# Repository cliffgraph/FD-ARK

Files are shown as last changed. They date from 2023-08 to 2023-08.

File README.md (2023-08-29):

# FD-ARK
by Harumakkin. 2023/08/29

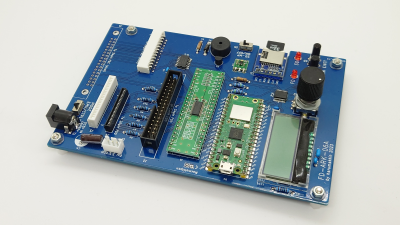
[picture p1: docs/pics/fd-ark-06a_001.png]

**fig.1 FD-ARK-06A**

## What's is this
FD-ARKは、FDDコントローラー＆FDDエミュレーターです。エミュレーターもしくはコントローラの二つの機能を持ち、基板上にある MODE SWによってどちらの機能を使用するかを利用者が選択します。

### （A）FDDコントローラーとしての機能
- MODE SWを"CTRL"にして電源を入れると、FD-ARKはFDDコントローラーとして動作します
- FD-ARKにFDD（フロッピーディスクドライブ）を接続し、2DDフロッピーディスク[^1]から全トラックデータを読み込んでSDカードに保存することができます。保存したデータをフロッピーに書き戻すこともできます。
- SDカード内でフロッピーディスク毎にフォルダ分けする機能がありますで、複数のフロッピーディスクを読み込、SDカードに保存することができます。
- 保存するフォルダは番号で管理されており、ロータリーエンコーダをつまんで回すことでその番号を選ぶことができます。
[^1]:2HDフロッピーディスクには対応していません。

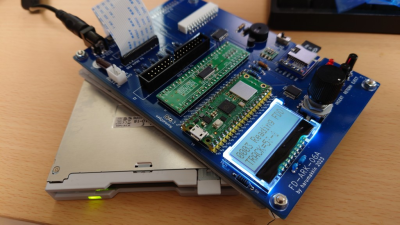
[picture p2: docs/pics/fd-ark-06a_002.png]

**fig.2 FD-ARK-06A with floppy disk drive**

### （B）FDDエミュレーターとしての機能
- MODE SWを"EMU"にして電源を入れると、FD-ARKはFDDエミュレーターとして動作します
- MSX turboR[^2]で、内臓FDDを取り外してFD-ARKを接続することで、FDDの代わりとして機能します。
- FDデータは、FDDコントローラー機能であらかじめSDカード内に保存しておく必要があります。
- MSX本体にアクセスさせるFDデータは、ロータリーエンコーダを回して指定できます。
[^2]:FS-A1STのみで動作確認を行っています。MSX2+ FS-A1WX/FS-A1WSX, MSX turboR FS-A1GT でも動作するはずです。

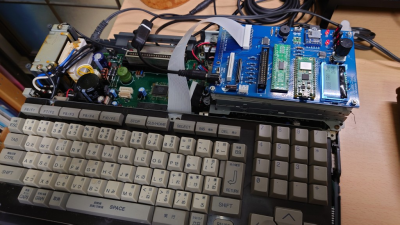
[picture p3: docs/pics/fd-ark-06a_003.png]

**fig.3 FD-ARK-06A with MSXturboR**

## 利用時の注意事項
- MODE SWに切り替えはFD-ARKの電源が切れているときのみ行うことができます。
- また、MSX本体にFD-ARKをつないだままFDDコントローラーに切り替えたり、FDDをFD-ARKをつないだままFDDエミュレーターに切り替えないでください。MSX本体やFDD、FD-ARKが破損する可能性があります。
- MicroSDカードはFATで形式でフォーマットしてください
- イレギュラーなことへの対処はあまり対応していません、FDDアクセス中にフロッピーディスクを抜くとか、SDカードをアクセス中に抜くなどを行うと、FD-ARKやMSX本体がフリーズしたりします。

## FD-ARKを作る
部品表にある部品の収集、プリント基板の製造、組み立て、ファームウェアの書き込みの作業が必要です。完成品はありません。
PCBを発注できて、SOPチップをはんだ付けで来て、Raspberry Pi Picoにu2fファイルを書き込みができる必要があります。

## FD-ARKを使う
### フロッピーディスクを読み込んでＳＤカードに保存する方法(FDDコントローラー)
1. FD-ARKのMODE SWを "CTRL" に切り替えます
1. FD-ARKに、MicroSDカードを装着します。MicroSDカードはWindowsPCなどで事前に FAT 形式でフォーマットしてください。
1. FDDを装着します。FDDは、J2、J3、J4のいずれかのコネクタに接続します。使用実績のあるFDDとその接続箇所はTable 1を参照ンしてください。
1. FD-ARKに、DC5V電源（センタープラス）を接続して電源を入れます
1. LCD画面には、
0001(no file
[←FD][→FD]
と表示されているはずです。
[←FD] の部分が[(空欄)]で表示されている場合は、SD-WPスイッチをOFFに切り替えます。[←FD]が表示されるはずです。
SD-WPスイッチは、SDカードへの書込禁止／許可を切り替えるスイッチです。
1. 読み込みたいフロッピーディスクをFDDへ挿入します。念のためフロッピーディスクのライトプロテクトはＯＮしてください
1. ロータリーエンコーダーを回してフロッピーディスクから読み込んだデータを格納するフォルダを決めます。0001から9999まで選択できます。
1. [←FD] スイッチ（INSERTとシルク印字されているスイッチ）を押します。FDDから読み込みが開始されます。
1. 両面80トラック(全160トラック)の読み込みが完了すると、完了音が鳴り、Completed と表示されます。
1. EJECTとシルク印字されているスイッチを押して、元の画面に戻ります。
1. 格納されたフォルダでは、画面に"FD-DATA"と表示されます。
ex) 0001 FD-DATA
1. 別のFDを読み込みたい場合は、別のフォルダを選択して同様の操作を行います。（どの番号にどのF\フロッピーを読み込んだかは別途メモしておいてください）
1. SDカードをWindowsPCなどで参照すると、\FD-ARK\XXXX フォルダが生成されています。XXXXは保存先に選択したフォルダの番号です。
1. \FD-ARK\XXXX フォルダ内には、COMMENT.TXT と複数のTKnnnn-n.DAT ファイルが生成されています。
1. COMMENT.TXTはLCDに表示されるフォルダ名称が格納されています。編集することができます（半角英数字のみ）。COMMENT.TXTファイルに書き込まれた内容がLCDに表示されるようになります。
### フロッピーディスクへ書き戻す方法(FDDコントローラー)
1. ライトプロテクトをOFFしたフロッピーディスクをFDDに入れます。
1. フロッピーディスクへ書き込むディスクイメージを選択します。
1. [→FD]スイッチ（RETURNとシルク印字されているスイッチ）を押します。FDDへの書き込みが開始されます。

**Table 1. FDDコントローラー・モードで実績のあるFDD**
||型番|メーカー|備考|
|:-:|:-|:-|:-|
|J2|YD-702D-6238D|YE DATA|J8をFDDの電源につなげる|
|J2|D353M3D|MITSUMI|J8をFDDの電源につなげげる|
|J3|EME213MU|Matsushita Electronic Components|FFC 1.25mmピッチ,24ピン,電極逆面を使用する|
|J4|YD-702J-6637J|YE DATA|FFC 1.00mmピッチ,26ピン,電極逆面を使用する||

### MSX本体に接続してフロッピーディスクの代わりとして使用する(FDDエミュレータ)
1. FD-ARKのMODE SWを "EMU" に切り替えます
1. FD-ARKに、MicroSDカードを装着します。事前にFDDコントローラーモードでなにがしかのフロッピーディスクイメージを保存しておく必要があります。
1. FD-ARKのJ5とMSX本体をフラットフレックスケーブルで接続します。動作確認を行った機種はFS-A1STのみです
1. FD-ARKに、DC5V電源（センタープラス）を接続して電源を入れます
1. ロータリーエンコーダーを回して、使用したいフロッピーディスクイメージを選択します。[INSERT]スイッチを押すと選択が確定します（フロッピーディスクをドライブに入れている状態になる）。INSERTされているディスクイメージは番号の前に"*" が表示されます。この状態でロータリーエンコーダーを回して別の番号を表示しても、"*"が表示されているフロッピーディスクイメージがそのまま使用されます。
ex) *0001 FD-DATA
1. [EJECT]スイッチを押すと、フロッピーディスクを取り出した状態にすることができます。
1. MSX本体の電源を入れます。
1. フロッピーディスクイメージを選択していて、そのイメージがブート可能な内容ならそのフロッピーディスクの内容が起動するはずです。

### MicroSDカード
FDDコントローラーモードでディスクイメージをSDカードに保存すると、SDカードにはFD-ARKフォルダが作成され、ディスクイメージはそのフォルダ内に作成される番号フォルダに下記込まれます
```
FD-ARK/
  ├ 0001/
  ├ 0002/
      :
```
番号フォルダ内には、160個のTKnnnn-n.DATファイルとCOMMENT.TXTファイルが格納されています。
１トラックにつき１つのファイルで、TKnnnn-n.DATはフロッピー１トラック分のデータですnnnnはトラック番号。-nはサイド番号です。
.DATファイルの先頭には少しの管理情報と、FDDのREAD DATA端子から出力されているデータを4MHzでサンプリングした情報がそのまま格納されています。
セクタ構造など一切確認作業を行わず生の出力データをそのまま保存しているので.DATファイルの内容が正しいかどうかの保障はありません。

## LICENSEと利用に関する注意事項
1. FD-ARKのファームウェアとそのソースコード、回路図データおよび資料ファイルは MIT License で配布されます。ただし、FD-ARK は、FatFsを使用しています。FatFsのソースコードの扱いに関してはFatFsのLICENSEに従ってください。
2. 本作品は同人ハードウェア＆ソフトウェアです。本作品の設計およびソフトウェアは品質を保証していません。MSX本体、フロッピーディスクドライブ、およびフロッピーディスクとそのデータが故障、破損したとしても自身で責任を負える方のみ本作品をご利用ください。特にハードウェアの製作を伴いますのでリスクがあります。製作の腕に自身のある方のみご利用ください。
3. 本作品の設計資料とソースコードの改変や改造、また、別の作品への利用、商用利用は自由です。ただし、1. 2.の制限を超える利用は各自でその責任と義務を負ってください。

## FD-ARKが使用しているソフトウェア
### FatFs
Copyright (C) 20xx, ChaN, all right reserved.
http://elm-chan.org/fsw/ff/00index_e.html

## 余談
1. FD-ARK製作の経緯：
当初、FDX68シールドという作品がBOOTHで売られていて[^3]、その装置はフロッピーディスクを読みだすことができ、またFDDエミュレータとして使用することもできるものらしいという漠然とした知識だけありました。そういう物があるのかぐらいに捉えていて、自身は必要性を感じていませんでした。しかしある時にふとゲーム保存協会のツイート[^4]が目にとまり、国立国会図書館@NDLJPフロッピーディスク長期保存対策に関する調査報告書というの知りました。これには様々な理由でフロッピーディスクは劣化するものであり、劣化するとフロッピーディスクは使用できなくなってしまうと書かれていました。自身が所有しているMSXに関するフロッピーディスクは30年を超えている物が多く、報告書との出会いは、結果、これらフロッピーディスクに危機感を募らせてしまうことになりました。FDX68シールド、ぜひとも欲しいとなったわけですが、いつも売り切れでこれがなかなか購入できません。調査報告書では似たようなツールにKryoFluxというものを紹介していました。それが公式ページから今でも購入可能と書かれていたので、購入してみることにしました。ただちゃんと調べてから購入すれば良かったのですが、てっきりFDX68のようにKryoFluxにもFDDエミュレータの機能があると思い込んでいてこれが失敗でした。発注後に取説書読んでそれに気が付いたわけですが、同時にFDDって意外とシンプルな仕組みなんだとその時に知りました。これならKryoFluxで読み込んだデータを使用するFDDエミュレータを自分でも作れるだろう、いや作ってしまえと思うに至りました。しっかり作ろうとすると細部が大変になりますのでフロッピーディスクのイメージ化機能もいっしょに作ってしまえば、データフォーマットも独自定義できるしもっと楽に作れると思い、結果、今回のFD-ARKになりました。KryoFluxはKryoFluxで、FD-ARKが失敗した時のためにとフロッピーディスクのイメージ化に今でも使用しています。また、FD-ARKで読み出して、そして書き出した後に、正しく読み書きできているかをKryoFluxでチェックするなんてことに使用しています。
自分自身が所有するフロッピーディスクのためだけに作成したので、3.5"2DD以外の対応は考えていません。
[^3]: https://booth.pm/ja/items/4451666
[^4]: https://twitter.com/gamepres/status/1648638490765295619

2. FDアーカイバを意味した"FD-ARC"と命名するつもりが、間違って"FD-ARK"と名付けてしまいました。ただ、"ARK"は聖書に出てくる十戒石板をおさめた箱を意味するので、大事な物をしまっておくという意味で FD-ARK のままとしました。

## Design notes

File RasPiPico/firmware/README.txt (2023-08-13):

ビルドの方法

> mkdir build
> cd build
> cmake -G "NMake Makefiles" ..
> nmake

build/fd-ark/に、fd-ark.uf2　が生成される.

2023/6/11 Harumakkin.

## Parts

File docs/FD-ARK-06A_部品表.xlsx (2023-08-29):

 |  |  |  |  |  | 2023-08-29
FD-ARK-06A
記号 | 型番 | 個数 | 部品スペック、他 | 購入元 |  | URL | 備考
C1, C2, C4 | 104 | 3 | セラミックコンデンサ 0.1uF
C3 | 105 | 1 | セラミックコンデンサ 1uF
C5 | 100uF | 1 | 電解コンデンサ 100uF
J1 | HIF3BA-34PA-2.54DS(63) | 1 | ボックスヘッダ34P(L形・MILスタンダード) | 千石電商 | ー | https://www.sengoku.co.jp/mod/sgk_cart/detail.php?code=6AD3-6HHL
J2 | 217034SE | 1 | ボックスヘッダ 34P 基板取付け【217034SE】 | マルツオンライン | ー | https://www.marutsu.co.jp/pc/i/10624/
J8 | S3B-XH-A(LF)(SN) | 1 | 【2.5mm】XHコネクタ 基板用ポスト 3P L型 | 千石電商 |  | https://www.sengoku.co.jp/mod/sgk_cart/detail.php?code=6AN6-ABMD
D1 | 1N4001 | 1 | 整流用ダイオード | 千石電商 |  | https://www.sengoku.co.jp/mod/sgk_cart/detail.php?code=EEHD-4V5C
IC1 | TC74HC07AF(F) | 1 | 6回路 バッファ オープンドレイン CMOS SOP14 | マルツオンライン | ー | https://www.marutsu.co.jp/pc/i/444802/
IC2 | MCP23S08-E/SS | 1 | IC XPNDR 10MHZ SPI 20SSOP | マルツオンライン | ー | https://www.marutsu.co.jp/pc/i/13274024/
J3 | 24FE-BT-VK-N | 1 | JST FPC/FFC コネクタ、24極、1.25mm、スルーホール | マルツオンライン | ー | https://www.marutsu.co.jp/pc/i/2565396/
J4 | HLW26S-2C7LF | 1 | CONN FFC FPC VERT 26POS 1MM PCB | マルツオンライン | ー | https://www.marutsu.co.jp/pc/i/12839834/
J5 | 24FE-ST-VK-N | 1 | JST FPC/FFC コネクタ、24極、1.25mm、スルーホール | マルツオンライン | ー | https://www.marutsu.co.jp/pc/i/2565397/
D2,D3 | LED | 2 | 低消費３ｍｍ赤色ＬＥＤ ６２５ｎｍ １ｍＡ 10個パック | 秋月電子 | I-16908 | https://akizukidenshi.com/catalog/g/gI-16908/
J6 | AE-LLCNV-LVCH16T245 | 1 | １６ビット双方向レベル変換モジュール | 秋月電子 | K-15696 | https://akizukidenshi.com/catalog/g/gK-15696/
J7 | MJ-179PH | 1 | ２．１ｍｍ標準ＤＣジャック（４Ａ） | 秋月電子 | C-06568 | https://akizukidenshi.com/catalog/g/gC-06568/
LCD1 | AQM1602Y-NLW-FBW | 1 | ＬＣＤモジュール １６×２行 白色バックライト付 白文字／黒背景 | 秋月電子 | P-12486 | https://akizukidenshi.com/catalog/g/gP-12486/ | AQM1602Y-FLW-FBWなどでもOK。お好みで
LS1 | PKM13EPYH4000-A0 | 1 | 圧電スピーカー（圧電サウンダ）（１３ｍｍ） | 秋月電子 | P-04118 | https://akizukidenshi.com/catalog/g/gP-04118/
Q1 | 2N7000 | 1 | ＭＯＳＦＥＴ ２Ｎ７０００ | 秋月電子 | I-09723 | https://akizukidenshi.com/catalog/g/gI-09723/
S1,S2,S3 | TVDP01-G73BB | 3 | タクトスイッチ ＴＶＤＰ０１－Ｇ７３ＢＢ（黒） | 秋月電子 | P-09824 | https://akizukidenshi.com/catalog/g/gP-09824/
S4,S5 | SS12D00G3 | 2 | スライドスイッチ １回路２接点 基板用 | 秋月電子 | P-15707 | https://akizukidenshi.com/catalog/g/gP-15707/
U1 | RaspberryPi Pico | 1 | RaspberryPi Pico | 秋月電子 | M-16132 | https://akizukidenshi.com/catalog/g/gM-16132/
－ | PHA-1x40SG | 1 | 細ピンヘッダ １×４０ （黒） ※RaspberryPi Pico、AE-LLCNV-LVCH16T245で使用する | 秋月電子 | C-06631 | https://akizukidenshi.com/catalog/g/gC-06631/
U2 | EC12E2420801 | 1 | ロータリーエンコーダ（２４クリックタイプ） | 秋月電子 | P-06357 | https://akizukidenshi.com/catalog/g/gP-06357/
U4 | AE-XC9306-3V3 |  | ＸＣ９３０６使用同期整流昇降圧ＤＣ／ＤＣコンバータキット ３．３Ｖ版 | 秋月電子 | K-16055 | https://akizukidenshi.com/catalog/g/gK-16055/
U3 | MicroSD Car Socket | 1 | Aideepen5個セットマイクロSDストレージ拡張ボードマイクロSDカードメモリシールドモジュール | Amazon | ー | https://www.amazon.co.jp/gp/product/B07MB9TS13/ref=ppx_yo_dt_b_asin_title_o03_s00?ie=UTF8&psc=1
R1,R2 | 10k | 2 | 1/4w 抵抗 |  | ー
R3,R4 | 4.7k | 2 | 1/4w 抵抗 |  | ー
R5-11 | 1k | 7 | 1/4w 抵抗 |  | ー
2023-08-12 | ・初版
2023-08-29 | ・C1, C2, C4, C3 の部品スペックの誤記を修正した
 | ・R3,R4の型番の誤記を修正した

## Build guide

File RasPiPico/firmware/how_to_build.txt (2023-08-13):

（１）Developer PowerShell for VS 2019 を開く
（２）fddpurser フォルダと同階層に、build フォルダを作成する。
（３）build フォルダへ移動する
（４）下記を実行する
	> set PICO_SDK_PATH "C:\Pico\pico-sdk"	*1
	> cmake -G "NMake Makefiles" ..
（５）ビルド実行
	> nmake
（６）build\fddpurser\ フォルダに、fddpurser.uf2 ファイルが出来上がればOK。

*1: "C:\Pico\pico-sdk" は、pico-sdkを格納している場所へのパス。環境に合わせて変更すること。

以上

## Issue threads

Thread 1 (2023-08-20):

抵抗（R3,R4）について

hoborakuten, 2023-08-20:
初めまして。

FD-ARKを作成したいと思い、部品を調達中ですが、一つ確認させてください。
抵抗（R3,R4）の抵抗は4.8kΩで正しいでしょうか。
当方電子工作初心者なのですが、4.8kΩの抵抗がどこの店にもありません。

ご助言いただけると非常に助かります。

cliffgraph, 2023-08-29:
こんにちは、ご指摘ありがとうございます。
部品表の記載ミスでした。すみません。

セラミックコンデンサ
C1, C2, C4 の部品スペック 0.01uF は  0.1uF が正しく、
C3 の部品スペック 0.1uF は  1uF が正しいです。

抵抗　R3,R4の型番は、4.8kは間違いで、4.7kが正しいです。

hoborakuten, 2023-08-29:
お忙しいところ、迅速な対応いただきありがとうございました。
動作確認の報告ができるよう作成していきたいと思います。

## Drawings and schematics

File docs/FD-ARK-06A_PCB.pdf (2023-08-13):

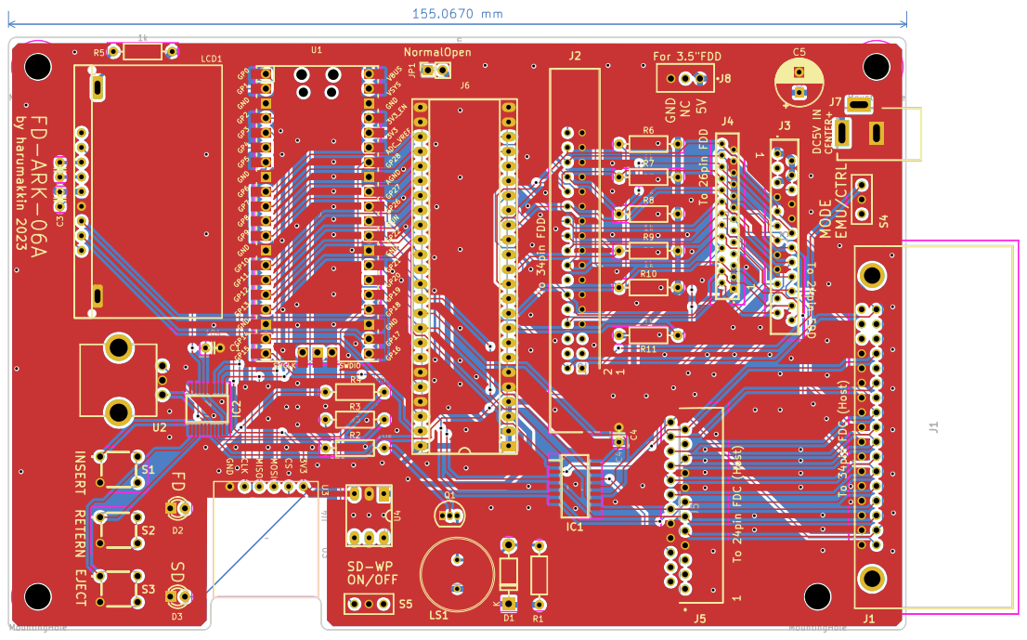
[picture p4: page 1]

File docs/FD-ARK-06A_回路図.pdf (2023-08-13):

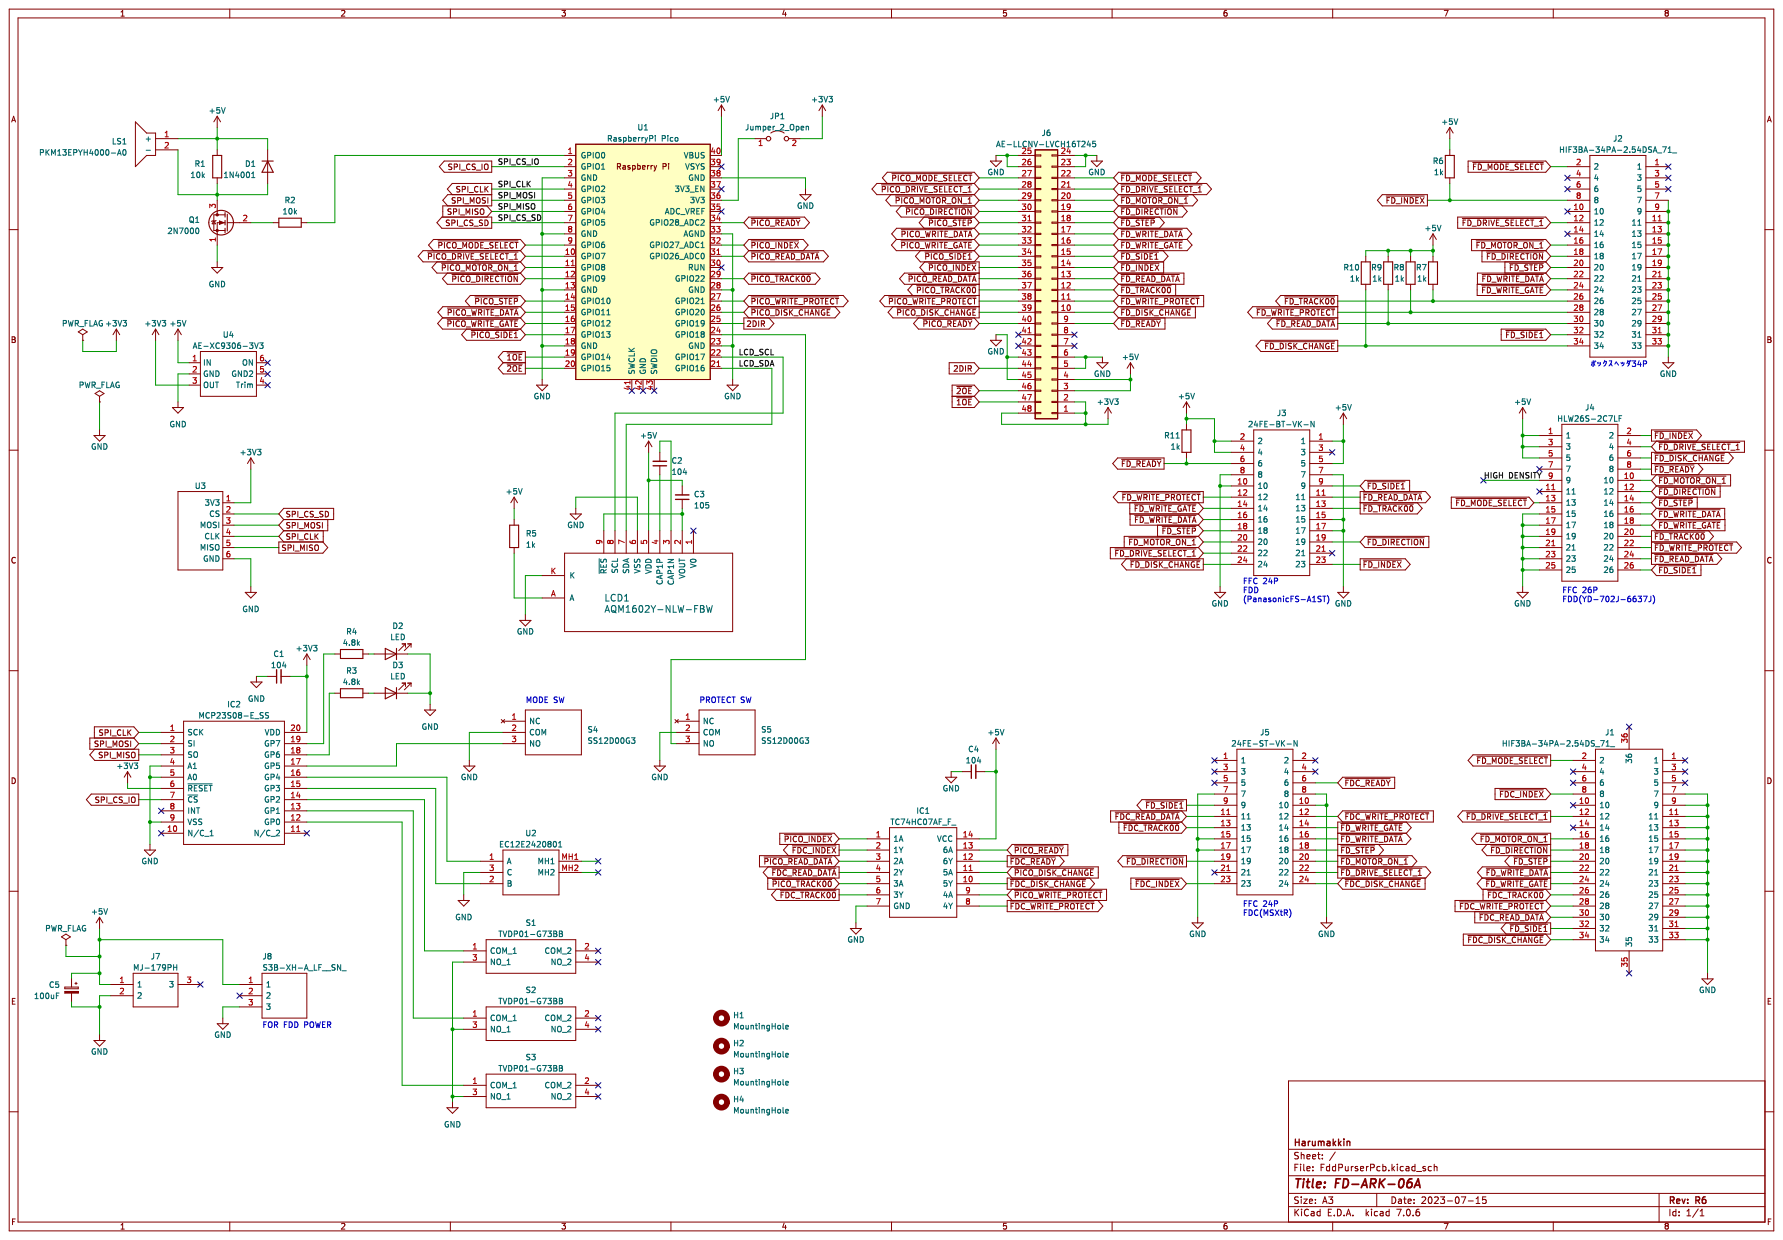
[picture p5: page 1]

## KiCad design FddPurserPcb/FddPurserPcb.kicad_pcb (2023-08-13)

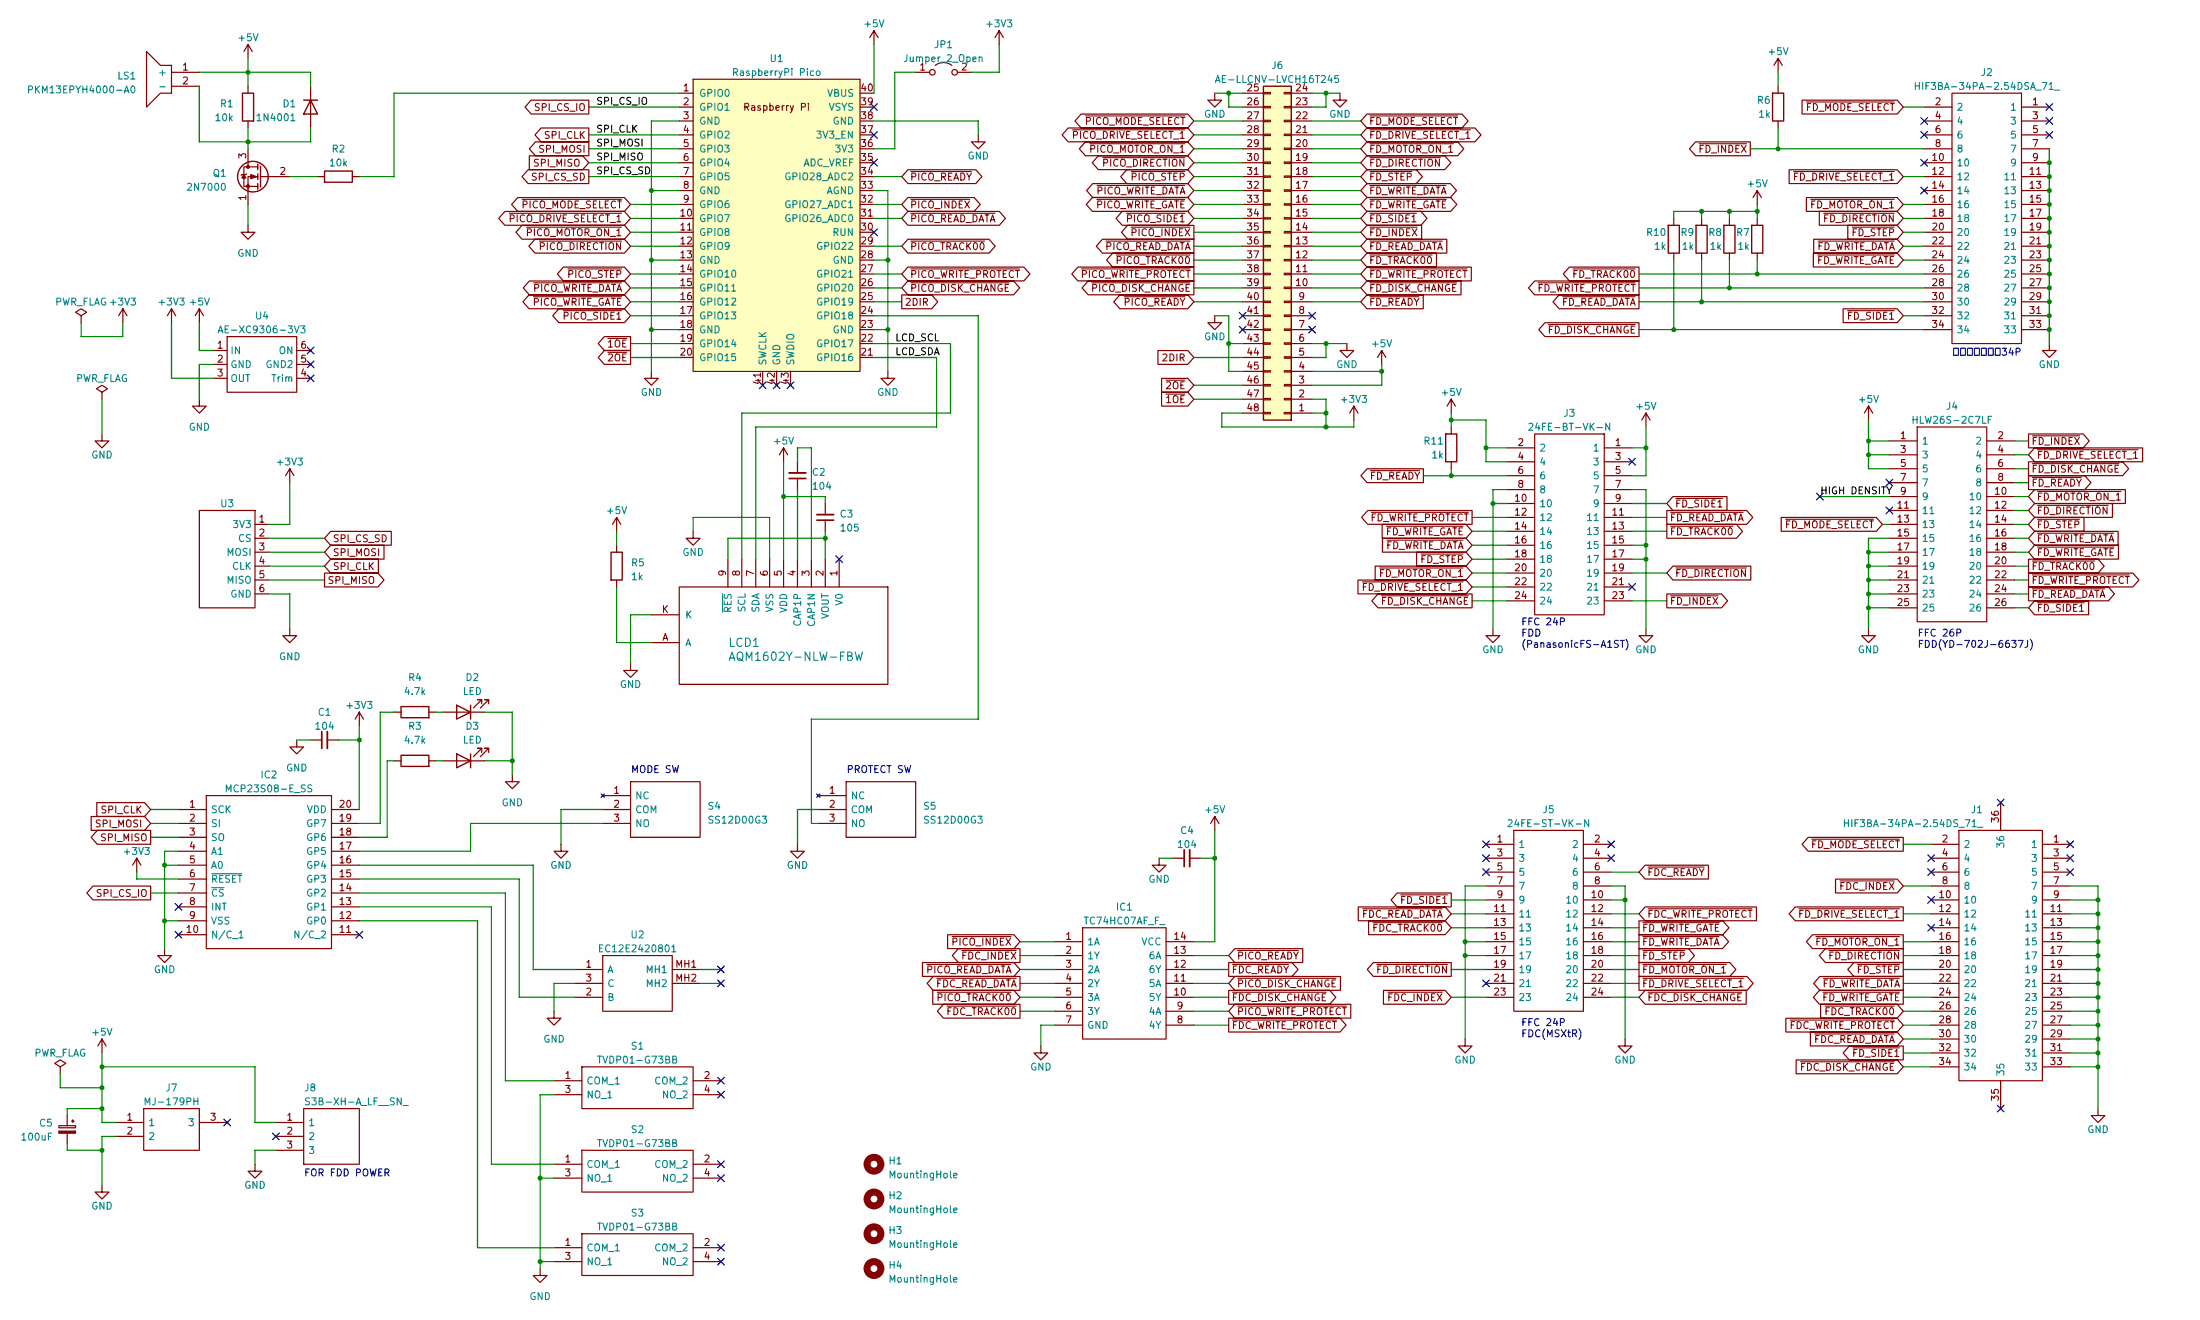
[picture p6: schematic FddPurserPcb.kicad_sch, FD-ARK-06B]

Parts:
C1, C2, C4: 104; C_Rect_L4.5mm_W3.5mm_P2.54mm
C3: 105; C_Rect_L4.5mm_W3.5mm_P2.54mm
C5: 100uF; CP_Radial_D8.0mm_P3.50mm
D1: 1N4001; D_DO-41_SOD81_P10.16mm_Horizontal
D2, D3: LED; LED_D3.0mm
H1, H2, H3, H4: MountingHole; MountingHole_4.3mm_M4
IC1: TC74HC07AF_F_; SOIC127P780X190-14N; Manufacturer_Part_Number TC74HC07AF(F)
IC2: MCP23S08-E_SS; SOP65P780X200-20N; Manufacturer_Part_Number MCP23S08-E/SS
J1: HIF3BA-34PA-2.54DS_71_; HIF3BA34PA254DS71; Manufacturer_Part_Number HIF3BA-34PA-2.54DS(71)
J2: HIF3BA-34PA-2.54DSA_71_; SHDR34W60P254_2X17_6250X850X2730P; Manufacturer_Part_Number HIF3BA-34PA-2.54DSA(71)
J3: 24FE-BT-VK-N; 24FEBTVKN; Manufacturer_Part_Number 24FE-BT-VK-N
J4: HLW26S-2C7LF; HLW26S2C7LF; Manufacturer_Part_Number HLW26S-2C7LF
J5: 24FE-ST-VK-N; 24FESTVKN; Manufacturer_Part_Number 24FE-ST-VK-N
J6: AE-LLCNV-LVCH16T245; DIP-48_W15.24mm_Socket_LongPads
J7: MJ-179PH; MJ179PH_N; Manufacturer_Part_Number MJ-179PH
J8: S3B-XH-A_LF__SN_; S3BXHALFSN; Manufacturer_Part_Number S3B-XH-A(LF)(SN)
JP1: Jumper_2_Open; PinSocket_1x02_P2.54mm_Vertical
LCD1: AQM1602Y-NLW-FBW; AQM1602Y-NLW
LS1: PKM13EPYH4000-A0; PKM13EPYH4002-B0; Manufacturer_Part_Number PKM13EPYH4000-A0
Q1: 2N7000; TO-92_Inline
R1, R2: 10k; R_Axial_DIN0207_L6.3mm_D2.5mm_P10.16mm_Horizontal
R3, R4: 4.7k; R_Axial_DIN0207_L6.3mm_D2.5mm_P10.16mm_Horizontal
R5, R6, R7, R8, R9, R10, R11: 1k; R_Axial_DIN0207_L6.3mm_D2.5mm_P10.16mm_Horizontal
S1, S2, S3: TVDP01-G73BB; TVDP01G73BB; Manufacturer_Part_Number TVDP01-G73BB
S4, S5: SS12D00G3; Manufacturer_Part_Number SS12D00G3
U1: RaspberryPi Pico; RPi_Pico_SMD_TH
U2: EC12E2420801; Manufacturer_Part_Number EC12E2420801
U3: Micro SD Card Socket
U4: AE-XC9306-3V3; AE-XC9306-xVx

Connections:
2DIR: J6.44, U1.25 (GPIO19)
+3V3: C1.2, IC2.6 (~RESET), IC2.20 (VDD), J6.1, J6.2, J6.48, JP1.2 (B), U3.1 (3V3), U4.3 (OUT)
+5V: C3.2, C4.2, C5.1, D1.1 (K), IC1.14 (VCC), J3.1, J3.2, J3.4, J3.5, J4.1, J4.3, J4.5, J6.3, J6.4, J7.1, J8.1, LCD1.5 (VDD), LS1.1 (+), R1.1, R5.1, R6.2, R7.2, R8.2, R9.2, R10.2, R11.2, U1.40 (VBUS), U4.1 (IN)
/HIGH DENSITY: J4.9
/LCD_SCL: LCD1.8 (SCL), U1.22 (GPIO17)
/LCD_SDA: LCD1.7 (SDA), U1.21 (GPIO16)
GND: C1.1, C4.1, C5.2, D2.1 (K), D3.1 (K), IC1.7 (GND), IC2.4 (A1), IC2.5 (A0), IC2.9 (VSS), J1.7, J1.9, J1.11, J1.13, J1.15, J1.17, J1.19, J1.21, J1.23, J1.25, J1.27, J1.29, J1.31, J1.33, J2.7, J2.9, J2.11, J2.13, J2.15, J2.17, J2.19, J2.21, J2.23, J2.25, J2.27, J2.29, J2.31, J2.33, J3.7, J3.8, J3.10, J3.15, J3.17, J4.15, J4.17, J4.19, J4.21, J4.23, J4.25, J5.7, J5.8, J5.10, J5.15, J5.17, J6.5, J6.6, J6.23, J6.24, J6.25, J6.26, J6.43, J6.45, J7.2, J8.3, LCD1.6 (VSS), LCD1.K, Q1.1 (S), S1.3 (NO_1), S2.3 (NO_1), S3.3 (NO_1), S4.2 (COM), S5.2 (COM), U1.3 (GND), U1.8 (GND), U1.13 (GND), U1.18 (GND), U1.23 (GND), U1.28 (GND), U1.33 (AGND), U1.38 (GND), U2.3 (C), U3.6 (GND), U4.2 (GND)
unnamed: D1.2 (A), LS1.2 (-), Q1.3 (D), R1.2
unnamed: D2.2 (A), R4.2
unnamed: D3.2 (A), R3.2
unnamed: IC2.12 (GP0), S3.1 (COM_1)
unnamed: IC2.13 (GP1), S2.1 (COM_1)
unnamed: IC2.14 (GP2), S1.1 (COM_1)
unnamed: IC2.15 (GP3), U2.2 (B)
unnamed: IC2.16 (GP4), U2.1 (A)
unnamed: IC2.17 (GP5), S4.3 (NO)
unnamed: IC2.18 (GP6), R3.1
unnamed: IC2.19 (GP7), R4.1
unnamed: JP1.1 (A), U1.36 (3V3)
unnamed: C2.2, LCD1.3 (CAP1N)
unnamed: C2.1, LCD1.4 (CAP1P)
unnamed: LCD1.A, R5.2
unnamed: C3.1, LCD1.2 (VOUT), LCD1.9 (~RES)
unnamed: Q1.2 (G), R2.2
unnamed: S5.3 (NO), U1.24 (GPIO18)
unnamed: R2.1, U1.1 (GPIO0)
SPI_CLK: IC2.1 (SCK), U1.4 (GPIO2), U3.4 (CLK)
SPI_CS_IO: IC2.7 (~CS), U1.2 (GPIO1)
SPI_CS_SD: U1.7 (GPIO5), U3.2 (CS)
SPI_MISO: IC2.3 (SO), U1.6 (GPIO4), U3.5 (MISO)
SPI_MOSI: IC2.2 (SI), U1.5 (GPIO3), U3.3 (MOSI)
~1OE: J6.47, U1.19 (GPIO14)
~2OE: J6.46, U1.20 (GPIO15)
~FDC_DISK_CHANGE: IC1.10 (5Y), J1.34, J5.24
~FDC_INDEX: IC1.2 (1Y), J1.8, J5.23
~FDC_READY: IC1.12 (6Y), J5.6
~FDC_READ_DATA: IC1.4 (2Y), J1.30, J5.11
~FDC_TRACK00: IC1.6 (3Y), J1.26, J5.13
~FDC_WRITE_PROTECT: IC1.8 (4Y), J1.28, J5.12
~FD_DIRECTION: J1.18, J2.18, J3.19, J4.12, J5.19, J6.19
~FD_DISK_CHANGE: J2.34, J3.24, J4.6, J6.10, R10.1
~FD_DRIVE_SELECT_1: J1.12, J2.12, J3.22, J4.4, J5.22, J6.21
~FD_INDEX: J2.8, J3.23, J4.2, J6.14, R6.1
~FD_MODE_SELECT: J1.2, J2.2, J4.13, J6.22
~FD_MOTOR_ON_1: J1.16, J2.16, J3.20, J4.10, J5.20, J6.20
~FD_READY: J3.6, J4.8, J6.9, R11.1
~FD_READ_DATA: J2.30, J3.11, J4.24, J6.13, R9.1
~FD_SIDE1: J1.32, J2.32, J3.9, J4.26, J5.9, J6.15
~FD_STEP: J1.20, J2.20, J3.18, J4.14, J5.18, J6.18
~FD_TRACK00: J2.26, J3.13, J4.20, J6.12, R7.1
~FD_WRITE_DATA: J1.22, J2.22, J3.16, J4.16, J5.16, J6.17
~FD_WRITE_GATE: J1.24, J2.24, J3.14, J4.18, J5.14, J6.16
~FD_WRITE_PROTECT: J2.28, J3.12, J4.22, J6.11, R8.1
~PICO_DIRECTION: J6.30, U1.12 (GPIO9)
~PICO_DISK_CHANGE: IC1.11 (5A), J6.39, U1.26 (GPIO20)
~PICO_DRIVE_SELECT_1: J6.28, U1.10 (GPIO7)
~PICO_INDEX: IC1.1 (1A), J6.35, U1.32 (GPIO27_ADC1)
~PICO_MODE_SELECT: J6.27, U1.9 (GPIO6)
~PICO_MOTOR_ON_1: J6.29, U1.11 (GPIO8)
~PICO_READY: IC1.13 (6A), J6.40, U1.34 (GPIO28_ADC2)
~PICO_READ_DATA: IC1.3 (2A), J6.36, U1.31 (GPIO26_ADC0)
~PICO_SIDE1: J6.34, U1.17 (GPIO13)
~PICO_STEP: J6.31, U1.14 (GPIO10)
~PICO_TRACK00: IC1.5 (3A), J6.37, U1.29 (GPIO22)
~PICO_WRITE_DATA: J6.32, U1.15 (GPIO11)
~PICO_WRITE_GATE: J6.33, U1.16 (GPIO12)
~PICO_WRITE_PROTECT: IC1.9 (4A), J6.38, U1.27 (GPIO21)

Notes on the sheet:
PROTECT SW
FFC 24P FDD (PanasonicFS-A1ST)
FOR FDD POWER
FFC 26P FDD(YD-702J-6637J)
FFC 24P FDC(MSXtR)
ボックスヘッダ34P
MODE SW

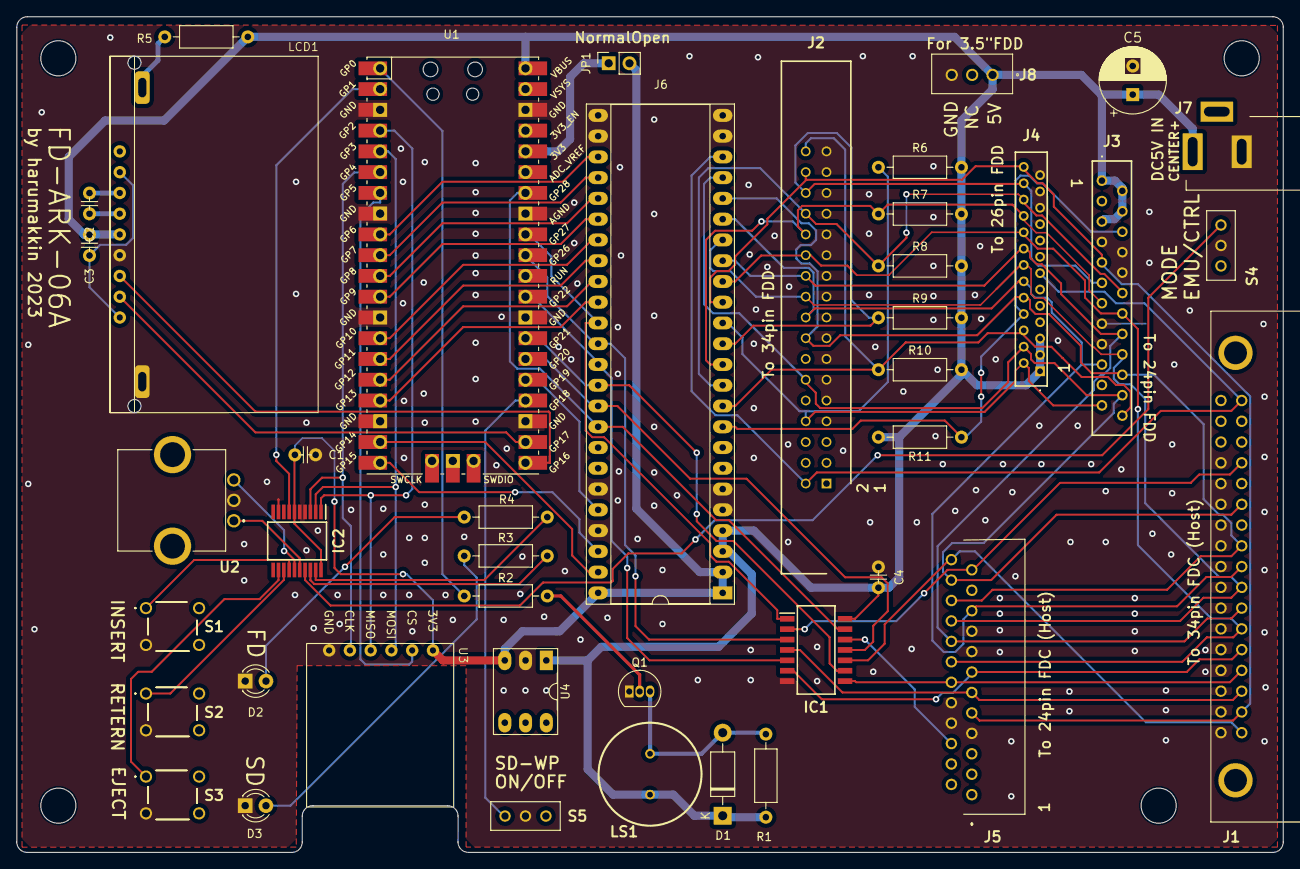
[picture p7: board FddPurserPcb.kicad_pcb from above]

Board: 2 copper layers, 154.9 x 102.2 mm, 46 parts (0 on the bottom side), 66 nets.

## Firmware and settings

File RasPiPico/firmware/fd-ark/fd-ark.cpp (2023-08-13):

/**
 * FD-ARK (RaspberryPiPico firmware)
 * Copyright (c) 2023 Harumakkin.
 * SPDX-License-Identifier: MIT
 */

// https://spdx.org/licenses/

#include <stdio.h>
#include "hardware/i2c.h"
#include "pico/multicore.h"
#include "ff.h"
#include "diskio.h"
#include "def_gpio.h"
#include "global.h"
#include "ctrlfd_core0_task.h"
#include "ctrlfd_core1_task.h"
#include "emu_core0_task.h"
#include "emu_core1_task.h"
#include "title.h"

struct INITGPTABLE {
	int gpno;
	int direction;
	bool bPullup;
	int	init_value;
};

static const INITGPTABLE g_GpioInitTableCommon[] = {
	{ GP_IO_SPI_CSN_PIN,			GPIO_OUT,	false, 1, },	// SPI CS-pin for I/O-Expander
	{ GP_BUZZER_PIN,				GPIO_OUT,	true,  0, }, 	// 無音時は0にしてBZに電圧がかからないようにしておく
	{ -1,							0,			false, 0, },
};


// FD 読み書きモード用のGPIO設定
static const INITGPTABLE g_CtrlFD_GpioTable[] = {
	// control-pin for FDD.
	{ GP_FDD_CTRL_MODE_SELECT_N,	GPIO_OUT,	false, 0, },
	{ GP_FDD_CTRL_DRIVE_SELECT_0_N,	GPIO_OUT,	false, 1, },
	{ GP_FDD_CTRL_MOTOR_ON_0_N,		GPIO_OUT,	false, 1, },
	{ GP_FDD_CTRL_DIRECTION_N,		GPIO_OUT,	false, 1, },
	{ GP_FDD_CTRL_STEP_N,			GPIO_OUT,	false, 1, },
	{ GP_FDD_CTRL_SIDE1_N,			GPIO_OUT,	false, 1, },
	{ GP_FDD_CTRL_WRITE_DATA_N,		GPIO_OUT,	false, 1, },
	{ GP_FDD_CTRL_WRITE_GATEA_N,	GPIO_OUT,	false, 1, },
	{ GP_FDD_STS_INDEX_N,			GPIO_IN,	false, 0, },
	{ GP_FDD_STS_READ_DATA_N,		GPIO_IN,	false, 0, },
	{ GP_FDD_STS_READY_N,			GPIO_IN,	false, 0, },
	{ GP_FDD_STS_TRACK00_N,			GPIO_IN,	false, 0, },
	{ GP_FDD_STS_WRITE_PROTECT_N,	GPIO_IN,	false, 0, },
	{ GP_FDD_STS_DISK_CHANGE_N,		GPIO_IN,	false, 0, },
	{ GP_CTRL_WP_N,					GPIO_IN,	true,  0, },
	// control-pin for level shifter.
	{ GP_CTRL_2DIR_N,				GPIO_OUT,	false, 1, },	// PICO 2A -> 2B FDD
	{ GP_CTRL_1OE_N,				GPIO_OUT,	false, 0, },	// ---- 開通
	{ GP_CTRL_2OE_N,				GPIO_OUT,	false, 0, },	// ---- 開通	
	// eot
	{ -1,							0,			false, 0, },
};

// FDDエミュレーター用のGPIO設定
static const INITGPTABLE g_Emu_GpioTable[] = {
	// control-pin for FDD.
	{ GP_FDD_CTRL_MODE_SELECT_N,	GPIO_IN,	false, 0, },
	{ GP_FDD_CTRL_DRIVE_SELECT_0_N,	GPIO_IN,	false, 0, },
	{ GP_FDD_CTRL_MOTOR_ON_0_N,		GPIO_IN,	false, 0, },
	{ GP_FDD_CTRL_DIRECTION_N,		GPIO_IN,	false, 0, },
	{ GP_FDD_CTRL_STEP_N,			GPIO_IN,	false, 0, },
	{ GP_FDD_CTRL_SIDE1_N,			GPIO_IN,	false, 0, },
	{ GP_FDD_CTRL_WRITE_DATA_N,		GPIO_IN,	false, 0, },
	{ GP_FDD_CTRL_WRITE_GATEA_N,	GPIO_IN,	false, 0, },
	{ GP_FDD_STS_INDEX_N,			GPIO_OUT,	false, 1, },
	{ GP_FDD_STS_READ_DATA_N,		GPIO_OUT,	false, 1, },
	{ GP_FDD_STS_READY_N,			GPIO_OUT,	false, 1, },
	{ GP_FDD_STS_TRACK00_N,			GPIO_OUT,	false, 1, },
	{ GP_FDD_STS_WRITE_PROTECT_N,	GPIO_OUT,	false, 1, },
	{ GP_FDD_STS_DISK_CHANGE_N,		GPIO_OUT,	false, 1, },
	{ GP_CTRL_WP_N,					GPIO_IN,	true,  0, },
	// control-pin for level shifter.
	{ GP_CTRL_2DIR_N,				GPIO_OUT,	false, 0, },	// PICO 2A <- 2B FDD
	{ GP_CTRL_1OE_N,				GPIO_OUT,	false, 1, },	// -||- 不通
	{ GP_CTRL_2OE_N,				GPIO_OUT,	false, 0, },	// ---- 開通	
	// eot
	{ -1,							0,			false, 0, },
};

static void setupGpio(const INITGPTABLE pTable[] )
{
	for (int t = 0; pTable[t].gpno != -1; ++t) {
		const int no = pTable[t].gpno;
		gpio_init(no);
		gpio_set_dir(no, pTable[t].direction);
		if( pTable[t].direction == GPIO_OUT)
			gpio_put(no, pTable[t].init_value);
		if (pTable[t].bPullup)
			gpio_pull_up(no);
	}
	return;
}

static bool timerproc_fot_ff(repeating_timer_t *rt)
{
	disk_timerproc();
	return true;
}

#include "pico/stdlib.h"
int main()
{
	stdio_init_all();
	setupGpio(g_GpioInitTableCommon);

	static repeating_timer_t tim;
	add_repeating_timer_ms (1/*ms*/, timerproc_fot_ff, nullptr, &tim);

	disk_initialize(0);

	sleep_ms(200);

	// Inirialize LCD
	g_Lcd.Initialize(i2c0, 0x3E, GP_SDA_PIN, GP_SCL_PIN);
	g_Lcd.SendCG();
	g_Lcd.Clear();

	// Display title
	g_Lcd.PutStrings(reinterpret_cast<const uint8_t*>(pTITLENAME), TITLENAME_SIZE);

	// Extender-I/O
	g_ExtIo.Initialize(GP_IO_SPI_CSN_PIN);

	// Determine the Mode by mode-switch
	const uint8_t portDt = g_ExtIo.GetPortRaw();
	g_bEmuMode = (portDt & ExtIO::SW_MODE) ? true : false;
	const char *pMode = (g_bEmuMode) ? "FD Emurator Mode" : "FDD Control Mode";
	g_Lcd.PutStrings(reinterpret_cast<const uint8_t*>(pMode), 16);
	sleep_ms(2000);

	// 
	if (g_bEmuMode) {
		setupGpio(g_Emu_GpioTable);
		multicore_launch_core1(Emu_Core1Main);
		Emu_Core0Main();
	} else {
		setupGpio(g_CtrlFD_GpioTable);
		multicore_launch_core1(CtrlFD_Core1Main);
		CtrlFD_Core0Main();
	}
	
	return 0;
}

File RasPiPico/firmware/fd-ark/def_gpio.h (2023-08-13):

/**
 * FD-ARK (RaspberryPiPico firmware)
 * Copyright (c) 2023 Harumakkin.
 * SPDX-License-Identifier: MIT
 */

#pragma once

#include "hardware/i2c.h"
#include "hardware/spi.h"


// --- Fdd Crisatl R2 ----

const uint32_t GP_FDD_CTRL_MODE_SELECT_N	= 6;	// 動作モード
													// 		2DDが挿入されているときは、この信号は意味をなさない（1.0Mモードで動作する）
													// 		2HDが挿入されているときは、L=1.6Mモード、H=2.0MBモードで動作する
const uint32_t GP_FDD_CTRL_DRIVE_SELECT_0_N	= 7;	// 
const uint32_t GP_FDD_CTRL_MOTOR_ON_0_N		= 8;	//
const uint32_t GP_FDD_CTRL_DIRECTION_N		= 9;	// ヘッドの移動方向(L=内側へ、H=外側へ)
const uint32_t GP_FDD_CTRL_STEP_N			= 10;	// １パルスでヘッドを別のトラックへ移動させる
const uint32_t GP_FDD_CTRL_WRITE_DATA_N		= 11;	// 書き込みデータ
const uint32_t GP_FDD_CTRL_WRITE_GATEA_N	= 12;	// 書き込みの指示
const uint32_t GP_FDD_CTRL_SIDE1_N			= 13;	// 書き込み面(L=Side:1, H=Side:0)

const uint32_t GP_FDD_STS_READY_N			= 28;
const uint32_t GP_FDD_STS_INDEX_N			= 27;
const uint32_t GP_FDD_STS_READ_DATA_N		= 26;
const uint32_t GP_FDD_STS_TRACK00_N			= 22;	// L=トラック0(最外周)にいる。
const uint32_t GP_FDD_STS_WRITE_PROTECT_N	= 21;
const uint32_t GP_FDD_STS_DISK_CHANGE_N		= 20;

const uint32_t GP_CTRL_1OE_N				= 14;	// 各種設定完了したら、L にして開通させる
const uint32_t GP_CTRL_2OE_N				= 15;	// 各種設定完了したら、L にして開通させる
const uint32_t GP_CTRL_WP_N					= 18;	// WRITE PROTECT SW, L=ON, H=OFF
const uint32_t GP_CTRL_2DIR_N				= 19;	// H固定とすること 2A -> 2B

const uint32_t GP_SDA_PIN 					= 16;	// GP16 = Pin.21 = SDA
const uint32_t GP_SCL_PIN 					= 17;	// GP17 = Pin.22 = SCL

const uint32_t GP_IO_SPI_CSN_PIN			= 1;	// CS for IO EXTENDER
const uint32_t GP_BUZZER_PIN				= 0;	// BUZZER

// SPI
#define SPIDEV spi0

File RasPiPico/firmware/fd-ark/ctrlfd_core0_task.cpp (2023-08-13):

/**
 * FD-ARK (RaspberryPiPico firmware)
 * Copyright (c) 2023 Harumakkin.
 * SPDX-License-Identifier: MIT
 */
// https://spdx.org/licenses/

#include <stdio.h>
#include <memory.h>
#include "pico/stdlib.h"
#include "pico/multicore.h"

 
#include "def_gpio.h"
#include "sdfat.h"
//
#include "global.h"
#include "ctrlfd_core0_task.h"
#include "ctrlfd_core1_task.h"
#include "gamen.h"
#include "timerobj.h"

static bool checkWriteProtect()
{
	gpio_put(GP_FDD_CTRL_DRIVE_SELECT_0_N, 0);
	sleep_ms(1);
	bool b = (gpio_get(GP_FDD_STS_WRITE_PROTECT_N)) ? false : true;
	gpio_put(GP_FDD_CTRL_DRIVE_SELECT_0_N, 1);
	return b;
}

static void requestFddControl(const TASKCMD cmd)
{
	sem_acquire_blocking(&g_TaskCmd.sem1);
	g_TaskCmd.cmds.Push(cmd);
	sem_release(&g_TaskCmd.sem1);
	return;
}

static const char *pSPACE = "                                ";

class GamenCtrlFD_FdSelect : public IGamen
{
private:
	enum class MEMOSTS
	{
		CHAKING,
		STORED,
		EMPTY,
	};
private:
	int encBinTemp;
	int curFdNo;
	int curFdNoOld;
	bool bSdWpOld;
	TimerObj delayDirCnt;
	TimerObj resetEnc;
	MEMOSTS memoSts, memoStsOld;
	int swOld;
	static const int SIZE_COMMENT = 32;
	char diskComment[SIZE_COMMENT+1] ;
private:
	GAMENINFO *pGamenInfo;

private:
	void encsFdNo(int encStep, int *pNo)
	{
		if( resetEnc.IsEffective() ) {
			if( resetEnc.IsTimeout() ) {
				resetEnc.Cancel();
				encBinTemp = 0;
			}
			else {
				return;
			}
		}

		// 選択FD番号の変更
		// エンコーダEC12E2420801は、１クリックで4増減する
		encBinTemp += encStep;
		if( 4 <= encBinTemp ){
			if( *pNo < MAX_FD_NO )
				++*pNo;
			resetEnc.Start(10);
		}
		else if( encBinTemp <= -4 ){
			if( MIN_FD_NO < *pNo )
				--*pNo;
			resetEnc.Start(10);
		}
		return;
	}

public:
	GamenCtrlFD_FdSelect()
	{
		encBinTemp = 0;
		curFdNo = MIN_FD_NO;
		curFdNoOld = -1;
		bSdWpOld = false;
		memoSts = MEMOSTS::CHAKING;
		memoStsOld = memoSts;
		swOld = 0;
		pGamenInfo = nullptr;
		return;
	}
	void Init(GAMENINFO *pG)
	{
		pGamenInfo = pG;
		return;
	}
	void Start()
	{
		curFdNoOld = -1;
		sleep_ms(300);
		// キーが押されていたら解放されるまでここで待つ。
		g_ExtIo.WaitFreeInput(ExtIO::SW_SW1|ExtIO::SW_SW2|ExtIO::SW_SW3);
		return;
	}
	void Main()
	{
		uint8_t sw = 0;
		int encStep = 0;
		g_ExtIo.GetInput(&sw, &encStep);
		const bool bSdWp = (gpio_get(GP_CTRL_WP_N)==0) ? true : false;
		// 選択FD番号の変更
		encsFdNo(encStep, &curFdNo);
		if (curFdNoOld != curFdNo){
			delayDirCnt.Start(300);
			memoSts = MEMOSTS::CHAKING;
		}

		BEEPSOUND beep = (curFdNoOld != curFdNo) ? BEEPSOUND::CLICK : BEEPSOUND::NONE;

		// LCD表示
		if ((swOld != sw) || (curFdNoOld != curFdNo) || (memoStsOld != memoSts) || (bSdWpOld != bSdWp)) {
			swOld = sw;
			curFdNoOld = curFdNo;
			memoStsOld = memoSts;
			bSdWpOld = bSdWp;
			const char *pMemoSts = "chking..";
			if (memoSts==MEMOSTS::EMPTY)
				pMemoSts = "(no file";
			else if (memoSts==MEMOSTS::STORED)
				pMemoSts = diskComment;
			char str[64+1];
			sprintf(str, "%c: %04d %-*s",
				(curFdNo<MAX_FD_NO)?'\x01':' ',		// x01 ↑
				curFdNo,								// DiskNo.
				8, pMemoSts);							// Comment

			char buff[32];
			memcpy(buff, pSPACE, 32);
			memcpy(&buff[0], &str[0], 16);
			buff[16] = (MIN_FD_NO<curFdNo)?'\x02':' ';		// x02 ↓
			if( bSdWp ) {
				memcpy(&buff[17], ": [   ] [\x03" "FD]", 13);
			}
			else {
				memcpy(&buff[17], ": [\x04" "FD] [\x03" "FD]", 13);
			}
			g_Lcd.Home();
			g_Lcd.PutStrings((uint8_t*)buff, 32);

			// [←FD]画面へ
			if (!(sw&ExtIO::SW_SW1)){
				if( bSdWp ) {
					beep = BEEPSOUND::ERROR;
				}
				else {
					pGamenInfo->SelectedFdNo = curFdNo;
					pGamenInfo->GamenNo = GAMENINFO::GAMENNO::CTRLFD_READ_FD;
					beep = BEEPSOUND::CLICK;
				}
			} 
			// [→FD]画面へ
			else if (!(sw&ExtIO::SW_SW2)){
				if (memoSts==MEMOSTS::EMPTY || checkWriteProtect()) {
					beep = BEEPSOUND::ERROR;
				}
				else{
					pGamenInfo->SelectedFdNo = curFdNo;
					pGamenInfo->GamenNo = GAMENINFO::GAMENNO::CTRLFD_WRITE_FD;
					beep = BEEPSOUND::CLICK;
				}
			} 
		}

		// memo.txtを読み込む -> diskComment, memoSts
		if (delayDirCnt.IsTimeout()) {
			delayDirCnt.Cancel();
			g_ExtIo.SetLED(ExtIO::LED_SD, ExtIO::LEDON);
			const bool b = ReadStoredMark(curFdNo, SIZE_COMMENT+1, diskComment);
			memoSts = (b) ? MEMOSTS::STORED : MEMOSTS::EMPTY;
			sleep_ms(5);
			g_ExtIo.SetLED(ExtIO::LED_SD, false/*点灯*/);
		}

		// 操作音
		if (beep != BEEPSOUND::NONE)
			BeepSound(beep);
		return;
	}
};

class GamenCtrlFD_ReadFDD : public IGamen
{
private:
	GAMENINFO *pGamenInfo;
	int swOld, sequenceNo;
public:
	GamenCtrlFD_ReadFDD()
	{
		pGamenInfo = nullptr;
		return;
	}
	void Init(GAMENINFO *pG)
	{
		pGamenInfo = pG;
		return;
	}
	void Start()
	{
		char str[32+1];
		sprintf(str,
			"%04d Read FDD?  " " [YES]  [NO]    ",
			pGamenInfo->SelectedFdNo);
		g_Lcd.Home();
		g_Lcd.PutStrings((uint8_t*)str, 32);
		swOld = 0;
		sequenceNo = 0;
		sleep_ms(300);
		// キーが押されていたら解放されるまでここで待つ。
		g_ExtIo.WaitFreeInput(ExtIO::SW_SW1|ExtIO::SW_SW2|ExtIO::SW_SW3);
		return;
	}
	void Main()
	{
		uint8_t sw = 0;
		g_ExtIo.GetInput(&sw, nullptr);

		BEEPSOUND beep = BEEPSOUND::NONE;

		// 実行の問い合わせ
		if (sequenceNo == 0 ) {
			if (swOld != sw) {
				swOld = sw;
				// [No], Cancel
				if ( !(sw&(ExtIO::SW_SW2)) || !(sw&(ExtIO::SW_SW3)) ) {
					pGamenInfo->GamenNo = GAMENINFO::GAMENNO::CTRLFD_TOP_MENU;	// 選択画面へ戻る
					beep = BEEPSOUND::CLICK;
				}
				// [YES]
				if ( !(sw&ExtIO::SW_SW1)) {
					sequenceNo = 1;
					beep = BEEPSOUND::CLICK;
				}
				//
			}
		}
		// 読み込み実行
		else if (sequenceNo == 1) {
			requestFddControl(TASKCMD::FDDCTRL_MOTOR_ON);
			sleep_ms(500);
			requestFddControl(TASKCMD::FDDCTRL_MOVE_TO_TRACK00);
			sleep_ms(1000);
			for (int tr = MIN_TRACK_NO; tr <= MAX_TRACK_NO; ++tr) {
				for (int side = 0; side < 2; ++side) {

					requestFddControl(
						(side==0)
						? TASKCMD::FDDCTRL_CHANGE_TO_SIDE_0 
						: TASKCMD::FDDCTRL_CHANGE_TO_SIDE_1);

					// LCD表示
					char str[32+1];
					sprintf(str,
						"%04d Reading FDD" "TRACK=%02d-%d      ",
						pGamenInfo->SelectedFdNo, tr, side);
					g_Lcd.Home();
					g_Lcd.PutStrings((uint8_t*)str, 32);

					// 読み込みを指示する
					sem_acquire_blocking(&g_TaskCmd.sem2);
					g_TaskCmd.bTrackDataOk = false;;
					sem_release(&g_TaskCmd.sem2);
					requestFddControl(TASKCMD::FDDCTRL_START_READ_TRACK);
					g_ExtIo.SetLED(ExtIO::LED_FD, ExtIO::LEDON);

					// 読み込み完了を待つ
					bool bWait = true;
					while(bWait) {
						sleep_ms(1);
						sem_acquire_blocking(&g_TaskCmd.sem2);
						if (g_TaskCmd.bTrackDataOk)
							bWait = false;
						sem_release(&g_TaskCmd.sem2);
					}
					g_ExtIo.SetLED(ExtIO::LED_FD, ExtIO::LEDOFF);
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

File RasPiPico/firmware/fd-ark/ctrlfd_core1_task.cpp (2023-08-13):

/**
 * FD-ARK (RaspberryPiPico firmware)
 * Copyright (c) 2023 Harumakkin.
 * SPDX-License-Identifier: MIT
 */
// https://spdx.org/licenses/

#include <stdio.h>
#include "pico/stdlib.h"
#include "def_gpio.h"
#include "fd-ark.pio.h"
#include "global.h"
#include "ctrlfd_core1_task.h"

static void ctrlFddMotorOn()
{
	gpio_put(GP_FDD_CTRL_DRIVE_SELECT_0_N, 0);
	gpio_put(GP_FDD_CTRL_MOTOR_ON_0_N, 0 );
	sleep_ms(500);
	return;
}

static void ctrlFddMotorOff()
{
	gpio_put(GP_FDD_CTRL_MOTOR_ON_0_N, 1 );
	gpio_put(GP_FDD_CTRL_DRIVE_SELECT_0_N, 1);
	return;
}

static void ctrlMoveHeadOneTrack()
{
	// step plus
	gpio_put(GP_FDD_CTRL_STEP_N, 0);
	sleep_us(2);
	gpio_put(GP_FDD_CTRL_STEP_N, 1);
	// 1-step完了後に4ms待つこと。
	sleep_ms(4);
	return;
}

static void ctrlMoveToTrack00()
{
	gpio_put(GP_FDD_CTRL_DIRECTION_N, 1/*外側へ*/);
	sleep_ms(4);

	for(;;){
		if( gpio_get(GP_FDD_STS_TRACK00_N) == 0 )
			break;
		ctrlMoveHeadOneTrack();
	}
	// seek完了後に18ms待つこと。
	sleep_ms(18);
	return;
}

static void ctrlSide(const uint32_t no)	// 1=side-0, 0=side-1  ← 直観と反するので注意
{
	gpio_put(GP_FDD_CTRL_SIDE1_N, no);
	sleep_us(100);
	return;
}

static void divideCode(const uint32_t v32, uint8_t *pIndex8, uint8_t *pData8)
{
	*pIndex8 =
		((v32 >> (15- 7)) & 0x0080) | ((v32 >> (13- 6)) & 0x0040) |
		((v32 >> (11- 5)) & 0x0020) | ((v32 >> ( 9- 4)) & 0x0010) | 
		((v32 >> ( 7- 3)) & 0x0008) | ((v32 >> ( 5- 2)) & 0x0004) |
		((v32 >> ( 3- 1)) & 0x0002) | ((v32 >> ( 1- 0)) & 0x0001);
	*pData8 = 
		((v32 >> (14- 7)) & 0x0080) | ((v32 >> (12- 6)) & 0x0040) |
		((v32 >> (10- 5)) & 0x0020) | ((v32 >> ( 8- 4)) & 0x0010) | 
		((v32 >> ( 6- 3)) & 0x0008) | ((v32 >> ( 4- 2)) & 0x0004) |
		((v32 >> ( 2- 1)) & 0x0002) | ((v32 >> ( 0- 0)) & 0x0001);
	return;
}

static void mergeCode(uint32_t *pTmp32, uint8_t dt, uint8_t gt)
{
	*pTmp32 = 
		(((uint32_t)gt&0x80)<<(15-7)) | (((uint32_t)dt&0x80)<<(14-7)) |
		(((uint32_t)gt&0x40)<<(13-6)) | (((uint32_t)dt&0x40)<<(12-6)) |
		(((uint32_t)gt&0x20)<<(11-5)) | (((uint32_t)dt&0x20)<<(10-5)) |
		(((uint32_t)gt&0x10)<<( 9-4)) | (((uint32_t)dt&0x10)<<( 8-4)) |
		(((uint32_t)gt&0x08)<<( 7-3)) | (((uint32_t)dt&0x08)<<( 6-3)) |
		(((uint32_t)gt&0x04)<<( 5-2)) | (((uint32_t)dt&0x04)<<( 4-2)) |
		(((uint32_t)gt&0x02)<<( 3-1)) | (((uint32_t)dt&0x02)<<( 2-1)) |
		(((uint32_t)gt&0x01)<<( 1-0)) | (((uint32_t)dt&0x01)<<( 0-0));
	*pTmp32 <<= 16;
	return;
}

static void readTrackAction(TASKCMD_PARAMS *pWk)
{
	// FDD読み込み用のPIO の開始
	PIO pio = pio0;
	uint offset = pio_add_program( pio, &pio_fddread_program );
	uint state_machine = pio_claim_unused_sm( pio, true );
	pio_fddread_program_init( pio, state_machine, offset, GP_FDD_STS_READ_DATA_N, 2);

	// FDDからの読み込み
	uint8_t index8 = 0, data8 = 0, index8old = 0;
	bool bOnSampling = false;
	uint32_t count = 0;
	uint8_t firstIndex8 = 0;
	while(count < SIZE_TRACK_DATA){
		uint32_t tmp32 = pio_sm_get_blocking(pio, state_machine);
		divideCode(tmp32, &index8, &data8);
		if (((index8 & 0x81) == 0x80) || (index8old == 0xff && index8 == 0) ) {
			if (!bOnSampling) {
				bOnSampling = true;
				firstIndex8 = index8;
			}
			else {
				pWk->TrackData.Binary[count++] = data8;
				pWk->TrackData.LastIndex8 = index8;
				break;
			}								
		}
		if (bOnSampling) {
			pWk->TrackData.Binary[count++] = data8;
		}
		index8old = index8;
	}
	pWk->TrackData.Count = count;

	// PIO 停止＆削除
	pio_sm_set_enabled(pio, state_machine, false);
	pio_sm_unclaim(pio, state_machine); 
	pio_remove_program(pio, &pio_fddread_program, offset);

	// firstIndex8、index信号の最初の8bitsが格納されている
	// この8bitsのmsbからONになっているビットを数える -> cnt
	// Binary[0]以降に格納されてるread信号の不要なビット数である
	int cnt = 0;
	for( int t = 0; t < 8; ++t){
		if (((firstIndex8>>(7-t))&0x01) == 0)
			break;
		cnt++;
	}
	// cnt の分だけビットをシフトしたデータを作成する
	if ( 0 < count) { 
		for (uint32_t c = 0; c < count; ++c) {
			const uint8_t t1 = pWk->TrackData.Binary[c+0] << cnt;
			const uint8_t t2 = pWk->TrackData.Binary[c+1] >> (8-cnt);
			pWk->TrackData.Binary[c+0] = t1 | t2;
		}
		pWk->TrackData.Binary[count-1] <<= cnt;
	}
	// トラックデータの最後のバイトデータ用の、WRITE GATE信号のビットを格納する
	pWk->TrackData.LastIndex8 = (pWk->TrackData.LastIndex8^0xff) | ((0xff<<cnt)^0xff);

	// 完了を通知
	sem_acquire_blocking(&pWk->sem2);
	pWk->bTrackDataOk = true;
	sem_release(&pWk->sem2);
	return;
}

static void writeTrackAction(TASKCMD_PARAMS *pWk)
{
	// トラックへの書き込みを開始する
	// ＦＤＤ読み込み用のPIO の開始
	PIO pio = pio0;
	uint offset = pio_add_program( pio, &pio_fddwrite_program );
	uint state_machine = pio_claim_unused_sm( pio, true );
	pio_fddwrite_program_init(
			pio, state_machine, offset,
			GP_FDD_CTRL_WRITE_DATA_N, 2,
			GP_FDD_STS_INDEX_N);

	// GATE&WRITE信号を作成してPIOに渡す
	uint32_t tmp32;
	for (uint32_t t = 0; t < pWk->TrackData.Count-1; ++t) {
		mergeCode(&tmp32, pWk->TrackData.Binary[t], 0x00);
		pio_sm_put_blocking(pio, state_machine, tmp32);
	}
	mergeCode(&tmp32, pWk->TrackData.Binary[ pWk->TrackData.Count-1], pWk->TrackData.LastIndex8);
	pio_sm_put_blocking(pio, state_machine, tmp32);
	pio_sm_put_blocking(pio, state_machine, 0xFFFFFFFF);
	while(!pio_sm_is_tx_fifo_empty(pio,state_machine));

	// PIO 停止＆削除
	pio_sm_set_enabled(pio, state_machine, false);
	pio_sm_unclaim(pio, state_machine); 
	pio_remove_program(pio, &pio_fddwrite_program, offset);

	// 完了を通知
	sem_acquire_blocking(&pWk->sem2);
	pWk->bTrackDataOk = false;
	sem_release(&pWk->sem2);
	return;
}

void CtrlFD_Core1Main()
{
	for (;;) {
		TASKCMD cmd;
		sem_acquire_blocking(&g_TaskCmd.sem1);
		bool b = g_TaskCmd.cmds.Pop(&cmd);
		sem_release(&g_TaskCmd.sem1);
		if (!b || cmd == TASKCMD::NONE)
			continue; 

		switch(cmd)
		{
			case TASKCMD::FDDCTRL_MOTOR_ON:
				ctrlFddMotorOn();
				break;
			case TASKCMD::FDDCTRL_MOTOR_OFF:
				ctrlFddMotorOff();
				break;
			case TASKCMD::FDDCTRL_MOVE_TO_TRACK00:
				ctrlMoveToTrack00();
				break;
			case TASKCMD::FDDCTRL_CHANGE_TO_SIDE_0:
				ctrlSide(1/*SIDE-0*/);
				break;
			case TASKCMD::FDDCTRL_CHANGE_TO_SIDE_1:
				ctrlSide(0/*SIDE-1*/);
				break;
			case TASKCMD::FDDCTRL_PREV_TRACK:
				gpio_put(GP_FDD_CTRL_DIRECTION_N, 1/*外側へ*/);
				sleep_ms(4);
				ctrlMoveHeadOneTrack();
				sleep_ms(18);
				break;
			case TASKCMD::FDDCTRL_NEXT_TRACK:
				gpio_put(GP_FDD_CTRL_DIRECTION_N, 0/*内側へ*/);
				sleep_ms(4);
				ctrlMoveHeadOneTrack();
				sleep_ms(18);
				break;
			case TASKCMD::FDDCTRL_START_READ_TRACK:
				readTrackAction(&g_TaskCmd );
				break;
			case TASKCMD::FDDCTRL_START_WRITE_TRACK:
				writeTrackAction(&g_TaskCmd);
				break;
			default:
				break;
		}
	}
	return;
}

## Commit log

2023-08-13 the first commit: FD-ARK's PCB data and firmware source code.
    [FD-ARK-06A_部品表.xlsx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]
2023-08-29 #1 部品表の誤記を修正した。ついでにREADME.mdの、開発経緯の文章も修正した
    [FD-ARK-06A_部品表.xlsx]
